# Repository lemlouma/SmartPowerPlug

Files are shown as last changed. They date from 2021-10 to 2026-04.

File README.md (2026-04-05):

# SmartPowerPlug
Transform an ESP8266 (version 01 or ESP01) card to a Web connected power switch in a context of smart spaces and IoT/WoT

## Usage
This code is used to transform any ESP8266 (version 01 or ESP01) card to a connected object (or Thing). The code allows preconfiguring the ESP01 to automatically connect to an existing  WiFi access point (A.P.) of the LAN or to make the ESP01 acts as an independent A.P.  that can be contacted directly contacted from any device using the Web. 

The code enables the access to the ESP01 from anywhere using the Web (HTTP protocol). Hence, using the programmed ESP01, anyone can control (turn ON or OFF) any electrical device connected with an electrical outlet to our object created on top of our programmed ESP01. At any time, the user can select the WiFi network he wants, using the implemented Web interface, or makes the object standalone in an A.P mode. All user preferences are saved in the persistent memory of the ESP8266 (EEPROM).<br/>
ESP8266 and breadboard prototyping
ESP8266 in real-world

<br/><br/>

## Requirements
For a detailed explanation about the code usage and the required connections of cables and GPIOs, please refer to the following videos. Please select the youtube subtitles tool for English, as the videos content is in French.<br/> In these videos, the cable connections required to connect the ESP8266 are explained using a breadboard for uploading and testing the code with the Arduino IDE through an Arduino Nano. For an independent connected object, you can integrate your programmed ESP8266-01 into the printed circuit board (PCB) detailed here:<br/><br/>
PCB

## Videos :<br/>
Part I (23min17s): http://1do.me/pZ <br/>
Part II (36min12s): http://1do.me/7n <br/>
Part III (36min15s): http://1do.me/eG <br/>
Partie IV [PCB] (34min11s): http://1do.me/3v <br/>
Web: http://www.lemlouma.com/papers/IoT_Tuto_SmartPowerPlug.html<br/>

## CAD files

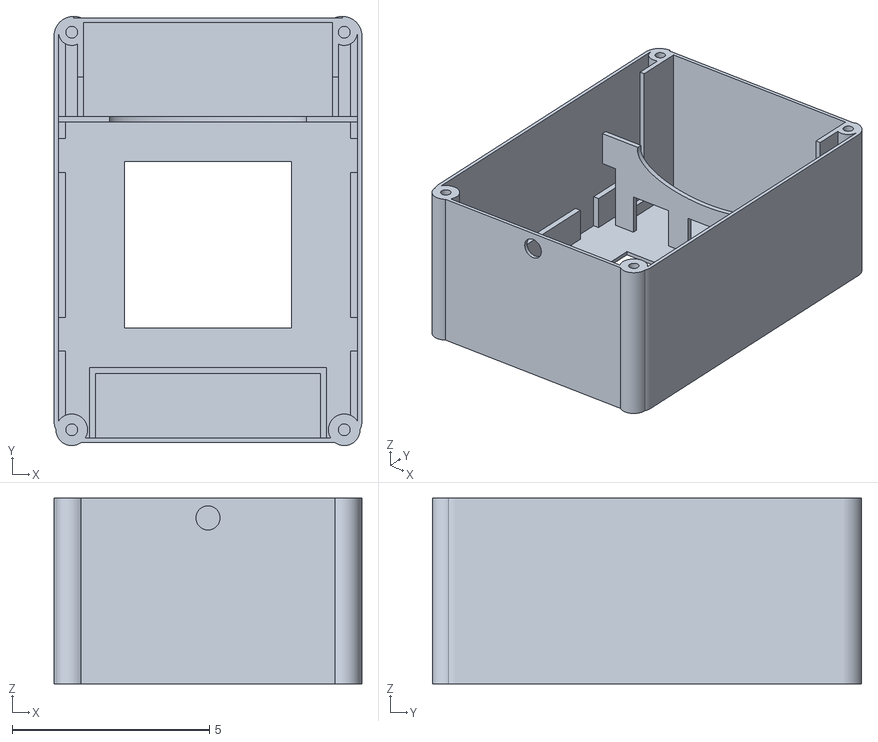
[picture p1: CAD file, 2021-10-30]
Modele3D_Bottom.stl
7.80 x 10.9 x 4.70

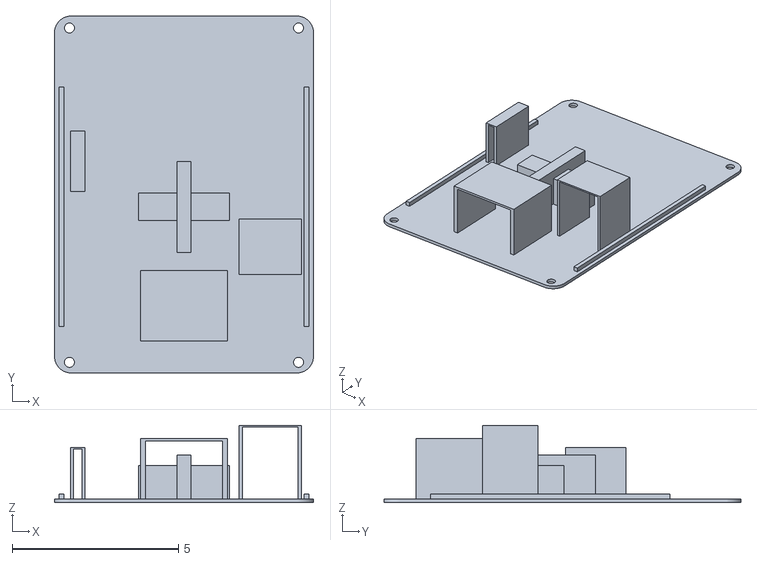
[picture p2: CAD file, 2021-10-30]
Modele3D_Top.stl
7.80 x 10.8 x 2.33

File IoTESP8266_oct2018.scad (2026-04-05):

//----------------------------- ATTACHES adaptés
deltaVide= 0.2;
rayonArrondi = 0.5;
epaisseurCubeContenant = 0.11;
largeur4attachesPriseFemelle = 0.18;
diametreCablePrise = 0.61;
//----------------------------- RELAY
largeurTrouRelay = 6.31;
profondeurTrouRelay = 2.42;
hauteurTrouRelay = 4.59;
epaisseurParoisRelay = 0.15;
//----------------------------- TRANSFO
largeurTrouTansfo = 5.7;
profondeurTrouTransfo = 1.68;
hauteurTrouTransfo = 1.15;
epaisseurParoisTransfo = 0.15;
decalageGaucheBord = 0.7;
//----------------------------- ESP8266
largeurTrouESP = 2.5;
largeurTrouESP2 = 0.54;
profondeurTrouESP1 = 1.15;
profondeurTrouESP2 = 1.5;
hauteurTrouESP = 0.59;
epaisseurParoisESP = 0.15;
decalageGaucheBordESP = 0.7;
//----------------------------- PRISE FEMELLE
profondeurCube = 6.21;//cm
hauteurCube = hauteurTrouRelay+epaisseurCubeContenant;
largeurCube = 7.22;

//----------------------------- CUBE Contenant
//variable solide
largeurCubeContenant = largeurCube+(2*largeur4attachesPriseFemelle)+(2*epaisseurCubeContenant);
profondeurCubeContenant = profondeurCube+(2*epaisseurCubeContenant)+profondeurTrouTransfo+profondeurTrouRelay+(2*epaisseurCubeContenant);
hauteurCubeContenant = hauteurCube;
//variable vide du cube solide
largeurCubeContenantVider = largeurCubeContenant-(2*epaisseurCubeContenant)-(2*largeur4attachesPriseFemelle);
profondeurCubeContenantVider = profondeurCubeContenant-(2*epaisseurCubeContenant);
hauteurCubeContenantVider = hauteurCubeContenant-epaisseurCubeContenant+deltaVide;

//attache verticale----------------------------
rayonAttacheCylind=0.4;
decal = 0.25;
hauteurAttacheCylind = hauteurCubeContenant;

//-------------------------------------------------------------------------
//
// Cube principale, vidé par les différents emplacements des composants
//
//-------------------------------------------------------------------------

difference(){
    union(){
        //Partie solide ------
        translate([0,(profondeurCubeContenant/2)-(profondeurCube/2)-profondeurTrouTransfo-2*
        epaisseurCubeContenant,0])
        translate([0,0,-epaisseurCubeContenant+hauteurCubeContenant/2])
        color("green")
        cube(size = [largeurCubeContenant, profondeurCubeContenant, hauteurCubeContenant], center = true, $fn=100); 
 
      
    }
    union(){
        //vidage simplement (et laisser de la matière pour les attaches de la rprise femelle) le cube contenant
        troueCubiquePourCubeContenant();
        
        troueHAUTCubiquePourCubeContenant();
        
        //vider les 4 attaches rectangulaire de la prise femelle
        4attachesPriseFemelle();
        
        //vider la base cubique de la prise femelle ---------
        troueCubiquePourPriseFemelle();
        
        //vidage des 4 coins
        4petitsCarresPourLaisserArrondi();
        
        //troue de la prise male de face
        trouPriseMale();
    }
}//difference(){ de CUBE contenant

4arrondiDuCube();//côtés arrondi
completerTroueArrondi();//remplir les trous de la base causé par le vidage des arrondis 
translate([0.065,0,0]) emplacementTransfo();
//emplacementESP8266();
attachesVerticalesFace();//pour le cube de base
attachesVerticalesArriere();//attaches cylindriques pour le cube de base
emplacementRelay();

//-------------------------------------------------------------------------
//
// FIN Cube principale, vidé par les différents emplacements des composants
//
//-------------------------------------------------------------------------


//-------------------------------------------------------------------------
//
// Couvercle 
//
//-------------------------------------------------------------------------

epaisseurBaseCouvert= epaisseurCubeContenant -0.05;

diametreVisCouvercle = 0.3;
deltaHauteurCouvercle = 1.5; //une hauteur pour visibilité lors de la conception
decalageVerticalPourVisibilite=((epaisseurCubeContenant+hauteurCubeContenant)/2)+deltaHauteurCouvercle;
translate ([0,0,decalageVerticalPourVisibilite])

difference(){
    union(){
        //Partie solide ------
        translate([0,(profondeurCubeContenant/2)-(profondeurCube/2)-        profondeurTrouTransfo-2*    
        epaisseurCubeContenant,0])
        translate([0,0,-epaisseurCubeContenant+hauteurCubeContenant/2])
        color("green")
        cube(size = [largeurCubeContenant, profondeurCubeContenant,         epaisseurCubeContenant], 
        center = true, $fn=100); 
        

        //le vidage des arrondis         
 
      
    }
    union(){
        //vidage des 4 coins
        4petitsCarresPourLaisserArrondi();
        //vider les trous pour vis de couvercle
            translate ([0,0,-3+hauteurCubeContenant+deltaHauteurCouvercle-decalageVerticalPourVisibilite])
                attachesVerticalesFaceVisagePourVis(diametreVisCouvercle);
            translate ([0,0,-3+hauteurCubeContenant+deltaHauteurCouvercle-decalageVerticalPourVisibilite])
                attachesVerticalesArriereVidagePourVis(diametreVisCouvercle);        

        //vidage pour tests =============================== MMMMMMMMMMMMMMMMMMMMMMMMMMMMMMMMMMMMMMMMMMMMM
        //translate ([0,4.2,6])
        //translate ([0,3.8,0])
        //    cube (size=[10,5,5], center=true);
        //translate ([0,-4,0])
        //    cube (size=[10,5,5], center=true);
        //fin vidage pour tests ============================= MMMMMMMMMMMMMMMMMMMMMMMMMMMMMMMMMMMMMMMMMMMMM
       
    }
}
//remplissage des coins arrondis et vidage de trous de vis
//**********************************************************
difference(){
    union(){
            //remplir les trous carrée de la base causé par le vidage carrée 
            //des coins
            translate ([0,-0.04,hauteurCubeContenant+deltaHauteurCouvercle])
                completerTroueArrondi();
    }
    union(){
        //vider les trous pour vis de couvercle
            translate ([0,0,-3+hauteurCubeContenant+deltaHauteurCouvercle])
                attachesVerticalesFaceVisagePourVis(diametreVisCouvercle);
            translate ([0,0,-3+hauteurCubeContenant+deltaHauteurCouvercle])
                attachesVerticalesArriereVidagePourVis(diametreVisCouvercle);

        //vidage pour tests =============================== MMMMMMMMMMMMMMMMMMMMMMMMMMMMMMMMMMMMMMMMMMMMM
        //translate ([0,4.2,6])
        //    cube (size=[10,5,5], center=true);
        //translate ([0,-4.2,6])
        //    cube (size=[10,5,5], center=true);
        //fin vidage pour tests ============================= MMMMMMMMMMMMMMMMMMMMMMMMMMMMMMMMMMMMMMMMMMMMM
        
    }
}//fin diff pour les coins
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

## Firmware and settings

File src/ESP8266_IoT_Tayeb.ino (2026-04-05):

/*

Connected Object (Thing) from A to Z
Author: Tayeb LEMLOUMA
Tayeb.Lemlouma@irisa.fr

Web : www.lemlouma.com
Github: github.com/lemlouma/
2018 - 2026 ©

This code is used to make any ESP8266 (version 01 or ESP01) card as a connected object (or Thing). The code allows preconfiguring the ESP01
to automatically connect to an existing  WiFi access point (A.P.) of the LAN or to make the ESP01 acts as an independent A.P.  that can be 
contacted directly from any device. The code enables access to the ESP01 from anywhere using the Web (HTTP protocol). Hence, using the 
programmed ESP01, anyone can control (turn ON or OFF) any electrical device connected with an electrical outlet to our object created on 
top of our programmed ESP01.
At any time, the user can select the WiFi network he wants or makes the object standalone in A.P mode. All user preferences are saved in 
the persistent memory of the ESP8266 (EEPROM).

For a detailed explanation about the code usage and the required connections of cables and GPIOs, please refer to the following videos. 
Please select the youtube subtitles tool for English, as the videos were made in French.
In these videos, the cable connections required to connect the ESP8266 are explained using a breadboard for uploading and testing the code 
with the Arduino IDE through an Arduino Nano. For an independent connected object, you can integrate your programmed ESP8266-01 into the 
printed circuit board (PCB) detailed here: http://www.lemlouma.com/papers/img/SmartPowerPlug_PCBtopSide.png.

Videos :
Part I (23min17s): http://1do.me/pZ 
Part II (36min12s): http://1do.me/7n 
Part III (36min15s): http://1do.me/eG
Part IV (34min11s): http://1do.me/3v 
Part V (35min05s): http://1do.me/Uk  
Web: http://www.lemlouma.com/papers/IoT_Tuto_SmartPowerPlug.html

*/


#include "ESP8266WiFi.h"
#include "EEPROM.h"
//#include "ESP8266WebServer.h"

String codeVersion = "Version 0.1a  Aug 2018 by Tayeb L. ©";

//Variables used for the user's configuration regarding the WiFi connection (make the ESP01 either an access point (A.P.) or a WiFi client)
String ssidWeb, passwordWeb=""; //the SSID and the password of the WiFi network as set by the user using the Web interface
String listeReseauxWifi=""; //contains the list of scanned WiFi APs (in an HTML form: using the HTML "select" tag)

//Variable en cas de tentative en cours de se connecter à un réseau Wifi
//Variable used to handle trying to connect to a Wifi network
String entrainDeSeconnecter = ""; //indicates that the current state of the connection is : at the beginning of the attempt
boolean orderDeConnexion = false; //indicates that we have just initiated a connection order to an existing A.P.

// Setup GPIO2
int pinGPIO2 = 2;  //the GPIO2 is used to control the output voltage of the electrical device connected to our smart object
int ledStatus = 0; //0=Off,1=On

String esp8266Mac = ""; //this variable will contains the MAC address of the ESP8266


WiFiServer WebServer(80); // run the Web server on the listening port 80
// Web Client
WiFiClient client; //used to handle Web clients (using Web browsers) who request our Web server
//--------------------------------------------------------------------------------------------------------------------
// Setup () general algorithm:
// 1. Display tge welcome message
// 2. We activate the GPIO-02 (used to control the power on of the electrical device connected to our object
// 3. Reading the memory of the ESP8266 (to consider the user preferences already saved: object mode (LAN or Internet) & preferred WiFi 
//    network (name and password)
// 4. Depending on the saved user preferences:
//      4.1. IF the object mode is "Internet" and there is a saved network name (SSID) and WiFi password
//           THEN
//                    Connect to the existing WiFi network (A.P.)
//                    [[
//                    IMPORTANT:
//                      - During the attempt to access an existing A.P. (by our object), the connection of web clients to our A.P. is 
//                      momentarily interrupted
//                      - We use a Web refresh (HTML refresh) to the same IP address of our object. This is done to have the new Web page 
//                      when our object is connected or becomes in A.P mode
//                      - Before attempting to connect to an existing A.P., our object sends a status of "being connected" ("en cours de 
//                      connexion") in the main web page configured with a regular HTML "refresh"
//                    ]]
//                    IF
//                      the attempt fails
//                    THEN
//                      become a WiFi A.P.
//           ELSE
//               become a WiFi A.P.
//      4.2. Run our web server to listen to Web client requests


//             
//--------------------------------------------------------------------------------------------------------------------
void setup() {
  //set empty the list of available WiFi networks
  listeReseauxWifi = "<select id=\"listeWi\" name=\"ssid\"><option value=\"\" selected>Mode local (pas d'Internet)</option></select>";
  Serial.begin(115200); //<----------------------------------------------------- this is for debug purposes, to be removed when all tests are completed
  delay(10);
  Serial.println();//<-------------------------------------------- this is for debug purposes, to be removed when all tests are completed
  Serial.println();//<-------------------------------------------- this is for debug purposes, to be removed when all tests are completed
  Serial.println("** WELCOME TO ESP8266 **");//<------------------ this is for debug purposes, to be removed when all tests are completed
  Serial.println(codeVersion);//<--------------------------------- this is for debug purposes, to be removed when all tests are completed

  // Setup the GPIO2 pin
  pinMode(pinGPIO2, OUTPUT);
  digitalWrite(pinGPIO2, LOW);//this depends on the connection of our prototype explained in the video : (+)Relay<->+PowerSupply AND (-)Relay<->GPIO-02)
                              //LOW will turn On the static solide relay (SSR)
  delay(1000); //wait a little bit !
  ledStatus = 1; 

  //****************************************** Start handling the EEPROM ***********************************************
  // SSID variable uses the first 50 chars, then, 
  // the PASWORD vraiable uses the following 50 chars
  EEPROM.begin(512);  //Initialize EEPROM: Max bytes of eeprom to use
  delay(100);
  //--------------------------------------------------------------------------------------------------------------------
  //                                                IMPORTANT
  //
  // This section must be executed ONLY ONCE to initialize the EEPROM before definitively issuing the ESP01
  // This section initializes the EEPROM (first 100 bytes) to 0
  // TODO: to avoid commenting and de-commenting the code (see my recomendations on : http://www.lemlouma.com/papers/IoT_Tuto_SmartPowerPlug.html):
  //        1. Write a special string in a specific place in the EEPROM, then 
  //        2. Test the existence of this specific string at the beginning of this code.
  //        IF 
  //            the specific string exists
  //        THEN 
  //            we have already initialized the EEPROM
  //        ELSE
  //            initialize the EEPROM as this section does
  //
  //--------------------------------------------------------------------------------------------------------------------
  /*
        //uncomment this section for the first use of the ESP 01
        //comment it for future usage
        //write 100 chars of '\0'
        for(int i=0;i<100;i++) //loop upto string lenght
        {
          EEPROM.write(0x0F+i,'\0'); //Write one by one with starting address of 0x0F
        }
        EEPROM.commit();    //Store data to EEPROM        
  */
  //--------------------------------------------------------------------------------------------------------------------

  //--------------------------------------------------------------------------------------------------------------------      
  // Test if a WiFi setting exist on the ESP01:
  // 1. Test if the first 20 tanks are at "#########"
  // 2. If so, we are in AP mode to configure
  // 3. Otherwise, we extract the SSID (the first 50 tanks from 0 to 49) and the Password (chars from 50 to 100)
  //--------------------------------------------------------------------------------------------------------------------          
        String ssid50char="", pass50char="";   
        //Here we dont know how many bytes to read (the real length of variables : ssid & password), so we use a terminating character
        Serial.println("Lecture de EPROM.."); //<-------------------------------- this is for debug purposes, to be removed when all tests are completed 
        for(int i=0;i<50;i++) 
        {
          char CC;
          CC = char(EEPROM.read(0x0F+i));
          if (CC != '\0'){
            ssid50char = ssid50char + CC; //Read one by one with starting address of 0x0F    
          }
        }  
        Serial.println("-- SSID : *"+ ssid50char+"*");  //<-------------------------------- this is for debug purposes, to be removed when all tests are completed 
        if (ssid50char == "\0\0\0\0\0\0\0\0\0\0\0\0\0\0\0\0\0\0\0\0\0\0\0\0\0\0\0\0\0\0\0\0\0\0\0\0\0\0\0\0\0\0\0\0\0\0\0\0\0\0") {
            //--------------------------------------------------------------------
            //         CASE 1: NO SAVED SETTINGS IN EEPROM 
            //--------------------------------------------------------------------            
            Serial.println("No existing WiFi setting!"); //<-------------------------------- this is for debug purposes, to be removed when all tests are completed 
            //Se mettre en mode accèss point
            WiFiAP();
            // Scan existing WiFi Networks to give the user the ability to select the WiFi network (Internet mode of the object)
            // NOTE : for performance considerations, we do not scan the network each time IF the user had already a preferred network (anyway, he/she can click on the scan link anytime)
            scanWifiNets(); //this updates the variable listeReseauxWifi            
            
        }else{
            //--------------------------------------------------------------------
            //         CASE 2: THERE IS A SAVED SETTINGS IN EEPROM 
            //--------------------------------------------------------------------           
            Serial.println("There is an existing WiFi setting!");//<-------------------------------- this is for debug purposes, to be removed when all tests are completed 
            //read the password from EPROM (SSID is already read)
            //Serial.println("Reading the password...");  
            for(int i=50;i<100;i++) 
            {
              char CC;
              CC = char(EEPROM.read(0x0F+i));
              if (CC != '\0'){
                  pass50char = pass50char + char(EEPROM.read(0x0F+i)); //Read one by one with starting address of 0x0F
              }    
            }  
            
            //Serial.println("-- Password : *"+ pass50char+"*");  //Print the text on the serial monitor            
            
            // use these two variables in HTML Edit and SELECT elements of the HTML page
            ssidWeb = ssid50char; 
            passwordWeb = pass50char;//+"\0";
            // prepare the HTML SELECT element of the Web page (the user can select the WiFi networj)
            listeReseauxWifi = "<select id=\"listeWi\" name=\"ssid\"><option value=\""+ssidWeb+"\" selected>"+ssidWeb+"</option><option value=\"\">Mode local (pas d'Internet)</option></select>";
            

            /*
            // The following is for debug purposes, to be used if you want
            Serial.println();
            Serial.println("PASWORD : ");
            Serial.println(passwordWeb);
            Serial.println("SSID : ");
            Serial.println(ssidWeb);            
            Serial.println("Liste : ");
            Serial.println(listeReseauxWifi);
            Serial.println();
            */
            // 1. Connection to the Wifi network
            // 2. IF fails THEN become A.P.
            //      Try to connect to WiFi with the values of SSID  and password
            //      If it fails, use the A.P. mode and inform the user that the connection is impossible
            entrainDeSeconnecter = "debutConnect"; //indicates that the current state of the connection is : at the beginning (i.e. we have just started a connection attempt)
            Serial.println("Status of the connection: "+entrainDeSeconnecter);//<-------------------------------- this is for debug purposes, to be removed when all tests are completed 
            orderDeConnexion = true; //this indicated that we just start an order to connect to an existing A.P.
            connectESPauReseauWiFiSinonDevientAP();                         
            
        }//end if (ssid50char == "\0\0\0\0\0\0\0\0\0\0\0\0\0\0\0\0\0\0\0\0\0\0\0\0\0\0\0\0\0\0\0\0\0\0\0\0\0\0\0\0\0\0\0\0\0\0\0\0\0\0") {
  
  EEPROM.end();                         
  //****************************************** End handling the EEPROM ***********************************************
  
  // Connect to the existing WiFi network AND take an IP address, the ESP8266 will be a WiFi "client" and in the same time a WEB "Server"
  // TODO: flashing a LED when trying to connext and fix it when connected (this will be good for the user's QoE)

  // Start the Web Server 
  WebServer.begin();
  Serial.println("Web Server started");                           // this is for debug purposes, to be removed when all tests are completed 

  // Print the IP address
  Serial.println("You can connect to the ESP8266 at this URL: "); // this is for debug purposes, to be removed when all tests are completed 
  Serial.println("http://");                                      // this is for debug purposes, to be removed when all tests are completed 
  Serial.print(WiFi.localIP());                                   // this is for debug purposes, to be removed when all tests are completed 
  Serial.print("/");                                              // this is for debug purposes, to be removed when all tests are completed
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
}//end void loop() {

//--------------------------------------------------------------------------------------------------------------------
// Make the ESP8266 in a WiFi Access Point mode, with the SSID : SmartPowerPlug_XX (XX: last two bytes of the MAC @ of the ESP01 to differentiate our ESP if there are several)
//--------------------------------------------------------------------------------------------------------------------
void WiFiAP()
{
  //Make the ESP8266 in a WiFi Access Point mode, with the SSID : SmartPowerPlug_XX (XX: last two bytes of the MAC @ of the ESP01 to differentiate our ESP if there are several)
  //---------------------------------------------------------------
  
  const char WiFiAPpwd[] = "admin";                             //we don't use it for the moment, our ESP8266 wil be an opened WiFi A.P.
  Serial.println();
  Serial.println("Setting Object into a A.P. Mode ... ");

  //Set a custom IP address for the ESP8266
  WiFi.mode(WIFI_AP_STA);
  IPAddress    apIP(192, 168, 1, 50);                           //<-------------------------------- this is for debug purposes, make it to 192.168.1.1 or 192.168.1.254 as recommended 
  WiFi.softAPConfig(apIP, apIP, IPAddress(255, 255, 255, 0));   // Subnet of the network : 255.255.255.0 (or /24)  

  //extract the last two bytes of the MAC @ of the ESP01 to differentiate our ESP if there are several
  uint8_t mac[WL_MAC_ADDR_LENGTH];
  WiFi.softAPmacAddress(mac);
  String macID = String(mac[WL_MAC_ADDR_LENGTH - 2], HEX) +
                 String(mac[WL_MAC_ADDR_LENGTH - 1], HEX);
  macID.toUpperCase();
  String AP_NameString = "SmartPowerPlug_" + macID; //append the last two bytes of the MAC @ of the ESP01 to the SSID of our ESP01 in order differentiate our ESP if there are several
  char AP_NameChar[AP_NameString.length() + 1];
  memset(AP_NameChar, 0, AP_NameString.length() + 1);
  for (int i=0; i<AP_NameString.length(); i++)
    AP_NameChar[i] = AP_NameString.charAt(i);

  
  //we don't use WiFiAPpwd for the moment, our ESP8266 wil be an opened WiFi A.P.
  boolean result = WiFi.softAP(AP_NameChar);//use "WiFi.softAP(AP_NameChar, WiFiAPpwd);" if you want to protect the ESP01 A.P. 
  if(result == true)
  {
    Serial.println("A.P. Ready");                 //<-------------------------------- this is for debug purposes, make it to 192.168.1.1 or 192.168.1.254 as recommended 
    IPAddress myIP = WiFi.softAPIP();
    Serial.println("AP IP address: ");            //<-------------------------------- this is for debug purposes, make it to 192.168.1.1 or 192.168.1.254 as recommended 
    Serial.println(myIP);                         //<-------------------------------- this is for debug purposes, make it to 192.168.1.1 or 192.168.1.254 as recommended 
  }else{
    Serial.println("A.P. mode Failed!");          //<-------------------------------- this is for debug purposes, make it to 192.168.1.1 or 192.168.1.254 as recommended 
  }
}

//------------------------------------------------------------------------------------------------------------------------------------------------
// Main function used to connect the ESP8266 to the WiFi network selected by the user, otherwise return to AP mode (ESP will be a WiFi A.P.)
//------------------------------------------------------------------------------------------------------------------------------------------------
void connectESPauReseauWiFiSinonDevientAP(){
        const char* ssidWebCHAR;
        const char* passwordWebCHAR;
        Serial.println();                         //<-------------------------------- this is for debug purposes, to be removed when all tests are completed 
        //entrainDeSeconnecter = "debutConnect";
        //WiFi.disconnect();
        //WiFi.mode(WIFI_STA);
        /*
        I uncommented the 2 previous lines for the following reason:
          - The logic was to use the WIFI_STA mode to connect the ESP8266 to the existing network, BUT NO:
          - In fact, when sending a connection request, the page does not load at all client side. See this error reported on 
          https://github.com/esp8266/Arduino/issues/1384 
          (message from bachi76 and hakeemta) : 

          Citation :
          "Just to confirm: Indeed, if WIFI_STA was set I experienced constant websocket connection interruptions, usually 1-2 times 
          / min. :
          
          WiFi.mode(WIFI_STA);
          WiFi.begin(..., ...);
          Setting WiFi.mode(WIFI_AP); has completely solved this, even though the ESP connects to the existing network as if were in 
          STA mode..
          
          WiFi.mode(WIFI_AP);
          WiFi.begin(..., ...);
          (I need to connect to an existing network - so using WIFI_AP is actually wrong, but apparently still connecting if the 
          specified network already exists).
          
          With WIFI_STA mode set I couldn't get a stable websocket connection. Tested with two devices to be sure. Looks like a bug to me. 
          @igrr ?        
          "
        
        */
        
        Serial.println("Connecting to ");                                                             //<-------------------------------- this is for debug purposes, to be removed when all tests are completed 
        Serial.println(ssidWeb);                                                                      //<-------------------------------- this is for debug purposes, to be removed when all tests are completed 
        ssidWebCHAR = ssidWeb.c_str(); passwordWebCHAR = passwordWeb.c_str();
        Serial.println("[SSID: *"+String(ssidWebCHAR)+"*, PASSWORD: *"+String(passwordWebCHAR)+"*]"); //<-------------------------------- this is for debug purposes, to be removed when all tests are completed 
        WiFi.begin(ssidWebCHAR, passwordWebCHAR);
        IPAddress ip(192,168,1,50); //We fix the IP address
        IPAddress gateway(192,168,1,102);   
        IPAddress subnet(255,255,255,0);   
        WiFi.config(ip, gateway, subnet);
        int tentative = 0;
        while (WiFi.status() != WL_CONNECTED) {
          delay(500);          //wait 500ms
          Serial.println("."); //<-------------------------------- this is for debug purposes (progression of WiFi connection), to be removed when all tests are completed 
          tentative = tentative+1;
          //try to connect during 20s (40x500ms), don't forget that the client Web page will be refreshed after 30 seconds
          if (tentative > 40){
             //if we made more than 40 try, we stop and go out, we don't insist!
             entrainDeSeconnecter = "echecConnect";
             break; 
          } 
        }
        Serial.println("");                                                                           //<-- this is for debug purposes, to be removed when all tests are completed 
        if (entrainDeSeconnecter !="echecConnect") entrainDeSeconnecter = "succesConnect";
        Serial.println("End of the WiFi connection process, status: "+entrainDeSeconnecter);          //<-- this is for debug purposes, to be removed when all tests are completed 
        orderDeConnexion = false;//to avoid triggering again a connection each received Web request
        
        //If we fail to connect the ESP8266 to an existing WiFi network, become in A.P mode
        if (entrainDeSeconnecter == "echecConnect"){
            Serial.println("Can not connect to WiFi, become a WiFi AP..");
            //become access point
            WiFiAP();

        }
}//end void connectESPauReseauWiFiSinonDevientAP(){
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

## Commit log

2021-10-30 Add files via upload
    Openscad File (code) of the 3D Model
    Code OpenScad du modèle 3D présenté dans le tutorial vidéo
    [IoTESP8266_oct2018.scad]
2026-04-05 Update comment for attachment section
    [IoTESP8266_oct2018.scad]
